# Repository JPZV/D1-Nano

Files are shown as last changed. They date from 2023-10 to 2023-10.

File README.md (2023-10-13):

# D1 Nano

This is a simple project of designs for a D1 Nano, a [D1 Mini](https://www.wemos.cc/en/latest/d1/d1_mini.html) replacement with a smaller size and compatible with ESP32 too!
While I don't have a shop myself, I give the necessary files for making your own free of charge, so feel free to printing your own PCB with your manufacture of choice.

## Advantages

 - Smaller size compared to the D1 Mini
 - All GPIO available with its respective labels
 - Just a few of components to be used
 - Can be powered by 3.3V using 3.3V Test point, or up to 12V by using the 5V Test point (5V is recommended thought)
 - Bigger GPIOs pads compared to the raw MCU
 - Easy to assemble

## Disadvantages

 - Not compatible with breadboards, all GPIOs in use must be soldered in your project
 - [External serial programmer](https://aliexpress.com/item/32842026979.html) must be used
 - No USB connectivity, nor powering by USB

## Assembling

Note: Every component, including the ESP32, can be hand soldered. The GND pad at the back of the ESP32 is not necessary to be soldered.

 0. Download the *.Garber.zip* file for your board in [Releases](https://github.com/JPZV/D1-Nano/releases/latest) and send it to your PCB manufacturer (like PCBWay)
 1. Any resistor marked by R* (R1, R2, R3, etc.) has to be filled with a **1206 10K SMD resistor**.
 2. Any capacitor marked by C* (C1, C2, C3, etc.) has to be filled with a **1206 100nF SMD capacitor** (also named as **1206 0.1uF SMD capacitor**)
 3. Both push buttons are **3x6x2.5mm SMD SPST**.
 4. The regulator (generally marked as **U2**) is an **AMS1117-3.3**.
 5. You can use any type of headers connector for the serial connection, even in any direction that you want. You can even use four Male Jumpers wires when you want to flash without soldering them and then removing them when you finish.
 6. And, for the main MCU, just use the ESP that you want, just be sure to download, buy and assemble the right board (e.g. Use the ESP32 Garber file if you want an ESP32 dev Board). Keep in mind that ESP8266 is also named as ESP12. This board was tested with an ESP12-F and a ESP32-D. The ESP32 Wrover may work but I cannot guarantee it

## Flashing

Note: An [External serial programmer](https://aliexpress.com/item/32842026979.html) is needed

 1. Connect the Serial Programmer to the serial header using Jump Wires.
    - Programmer 5V -> Board 5V
    - Programmer TX -> Board RX
    - Programmer RX -> Board TX
    - Programmer GND -> Board GND
 2. Connect the programmer to your computer
 3. Press and hold the **Reset** button.
 4. Then, press and hold the **Boot** button.
 5. Next, release the **Reset** button while holding the **Boot** button.
 6. Finally, release the **Boot** button. In some ESP32 you have to maintain the **Boot** button pressed while flashing. If you cannot flash your program, then try everything again from step 1 but don't release the **Boot** button until everything is correctly flashed.
 7. Start the Flash process in your program (VS Code, Arduino, ESPHome, Online flasher, etc.) and wait until it finishes.
 8. After it finishes correctly, do a single press in the **Reset** button.

## Contributing

Pull requests are welcome. For major changes, please open an issue first to discuss what you would like to change.

## License

This project uses [MIT license](/LICENSE). This means that you can do whatever you want with this project. You can even make your own board and sell it without needing to give me a commission. But, if you want, you always can [buy me a Coffe](https://ko-fi.com/jpzv5) :)

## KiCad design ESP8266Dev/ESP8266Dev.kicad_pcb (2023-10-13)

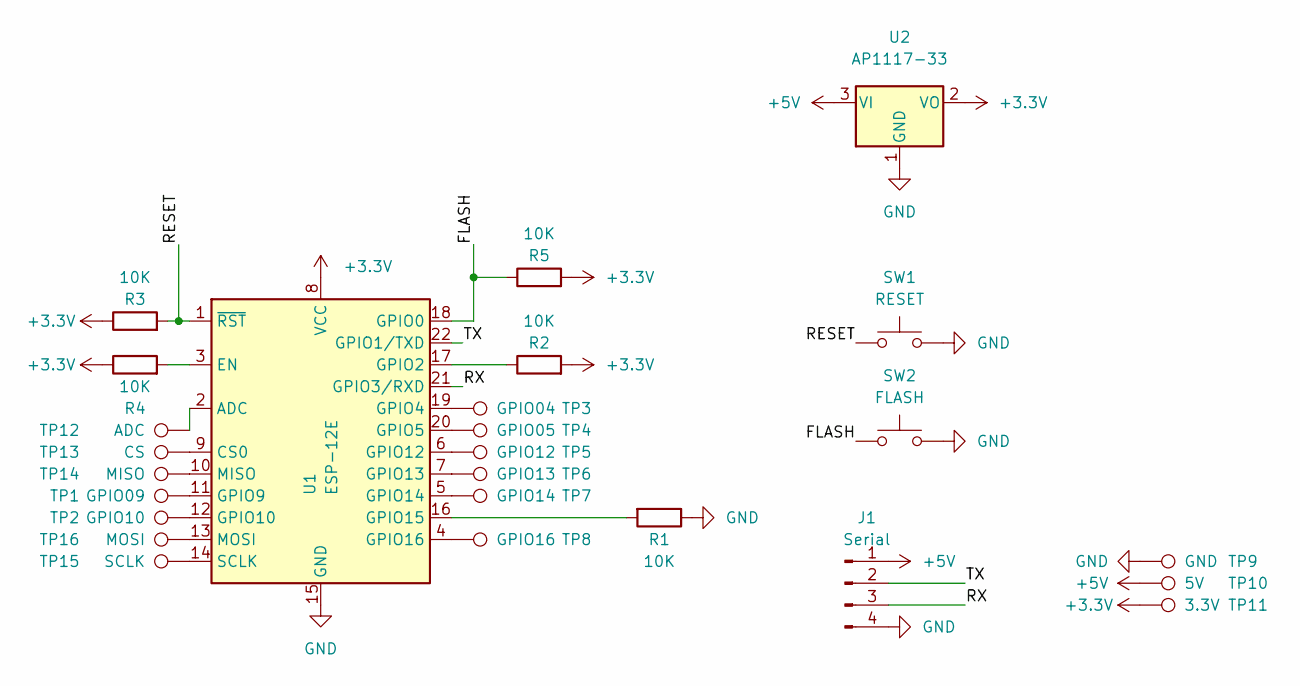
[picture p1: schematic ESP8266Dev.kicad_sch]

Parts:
J1: Serial; PinHeader_1x04_P2.54mm_Vertical
R1, R2, R3, R4, R5: 10K; R_1206_3216Metric_Pad1.30x1.75mm_HandSolder
SW1: RESET; SW_SPST_FSMSM
SW2: FLASH; SW_SPST_FSMSM
TP1: GPIO09; TestPoint_Pad_D2.0mm
TP2: GPIO10; TestPoint_Pad_D2.0mm
TP3: GPIO04; TestPoint_Pad_D2.0mm
TP4: GPIO05; TestPoint_Pad_D2.0mm
TP5: GPIO12; TestPoint_Pad_D2.0mm
TP6: GPIO13; TestPoint_Pad_D2.0mm
TP7: GPIO14; TestPoint_Pad_D2.0mm
TP8: GPIO16; TestPoint_Pad_D2.0mm
TP9: GND; TestPoint_Pad_D2.0mm
TP10: 5V; TestPoint_Pad_D2.0mm
TP11: 3.3V; TestPoint_Pad_D2.0mm
TP12: ADC; TestPoint_Pad_D2.0mm
TP13: CS; TestPoint_Pad_D2.0mm
TP14: MISO; TestPoint_Pad_D2.0mm
TP15: SCLK; TestPoint_Pad_D2.0mm
TP16: MOSI; TestPoint_Pad_D2.0mm
U1: ESP-12E
U2: AP1117-33; SOT-223-3_TabPin2

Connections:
+3.3V: R2.2, R3.1, R4.1, R5.2, TP11.1, U1.8 (VCC), U2.2 (VO)
+5V: J1.1, TP10.1, U2.3 (VI)
/FLASH: R5.1, SW2.1, U1.18 (GPIO0)
/RESET: R3.2, SW1.1, U1.1 (~RST)
/RX: J1.3, U1.21 (GPIO3/RXD)
/TX: J1.2, U1.22 (GPIO1/TXD)
GND: J1.4, R1.1, SW1.2, SW2.2, TP9.1, U1.15 (GND), U2.1 (GND)
unnamed: TP12.1, U1.2 (ADC)
unnamed: TP13.1, U1.9 (CS0)
unnamed: R4.2, U1.3 (EN)
unnamed: R2.1, U1.17 (GPIO2)
unnamed: TP3.1, U1.19 (GPIO4)
unnamed: TP4.1, U1.20 (GPIO5)
unnamed: TP1.1, U1.11 (GPIO9)
unnamed: TP2.1, U1.12 (GPIO10)
unnamed: TP5.1, U1.6 (GPIO12)
unnamed: TP6.1, U1.7 (GPIO13)
unnamed: TP7.1, U1.5 (GPIO14)
unnamed: R1.2, U1.16 (GPIO15)
unnamed: TP8.1, U1.4 (GPIO16)
unnamed: TP14.1, U1.10 (MISO)
unnamed: TP16.1, U1.13 (MOSI)
unnamed: TP15.1, U1.14 (SCLK)

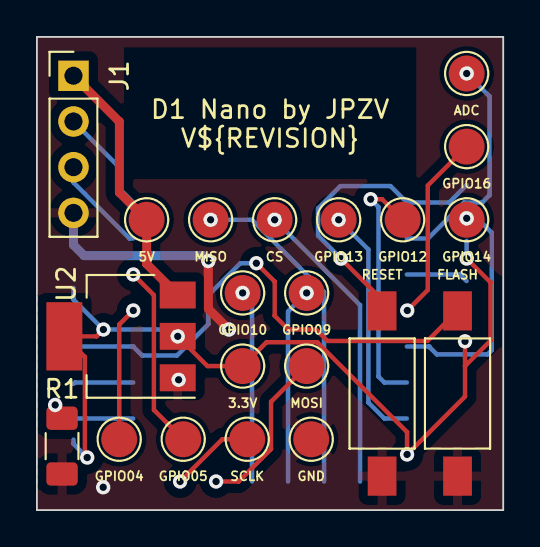
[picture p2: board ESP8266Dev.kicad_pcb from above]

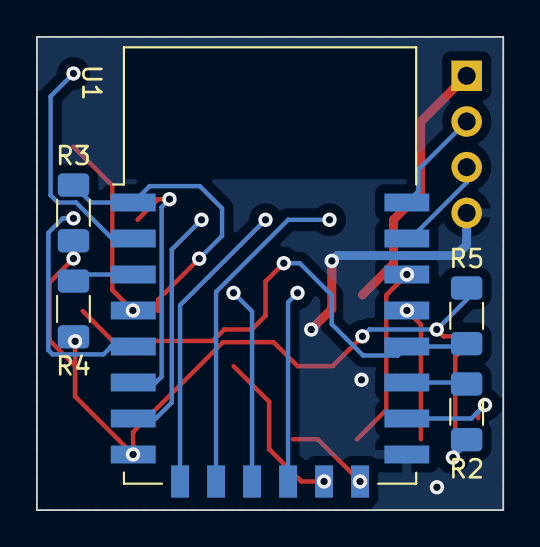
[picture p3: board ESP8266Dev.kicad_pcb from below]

Board: 2 copper layers, 25.9 x 26.3 mm, 26 parts (5 on the bottom side), 23 nets.

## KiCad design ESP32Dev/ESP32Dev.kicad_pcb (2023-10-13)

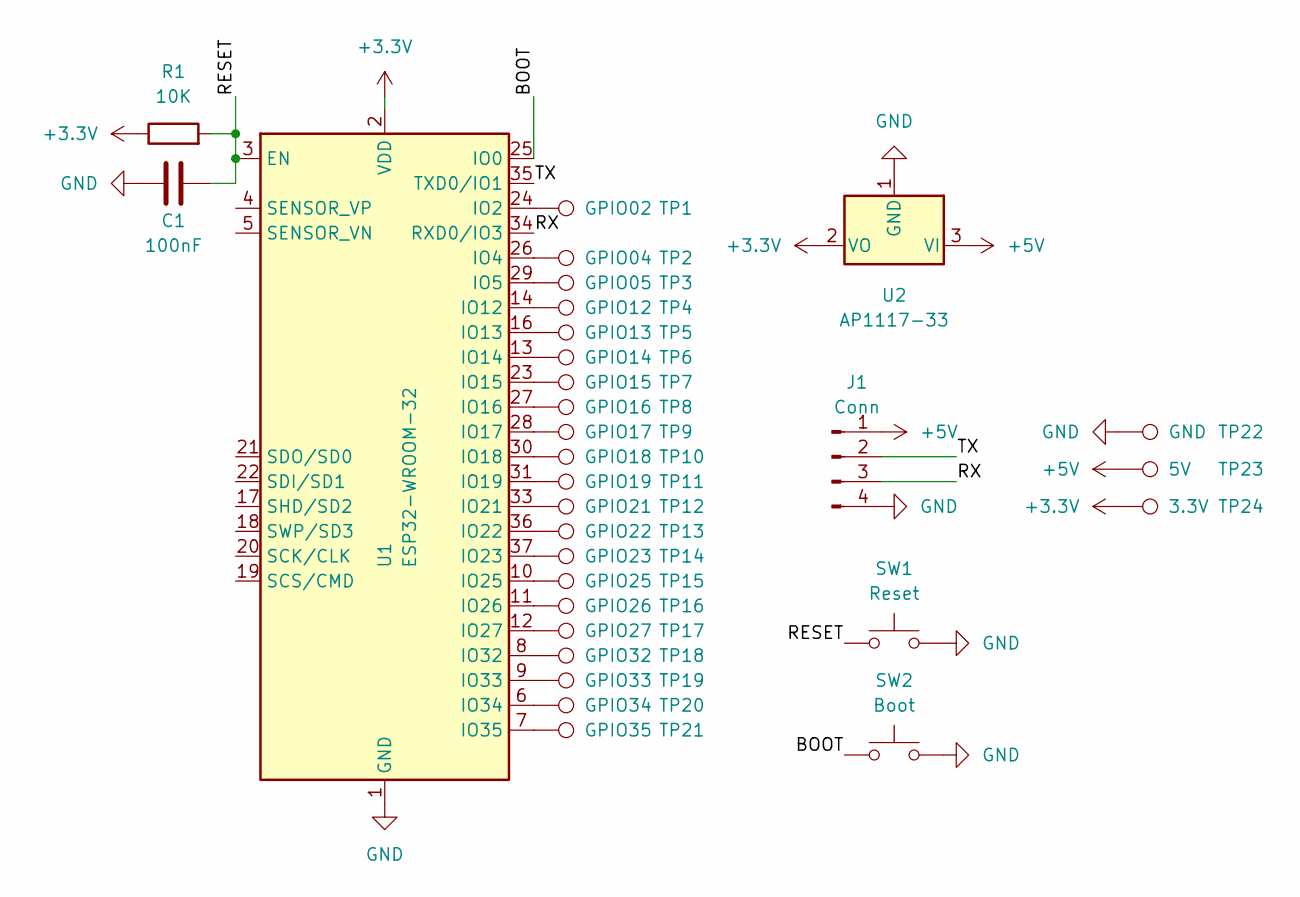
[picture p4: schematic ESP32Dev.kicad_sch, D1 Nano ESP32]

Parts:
C1: 100nF; C_1206_3216Metric_Pad1.33x1.80mm_HandSolder
J1: Conn; PinHeader_1x04_P2.54mm_Vertical
R1: 10K; R_1206_3216Metric_Pad1.30x1.75mm_HandSolder
SW1: Reset; SW_SPST_FSMSM
SW2: Boot; SW_SPST_FSMSM
TP1: GPIO02; TestPoint_Pad_D2.0mm
TP2: GPIO04; TestPoint_Pad_D2.0mm
TP3: GPIO05; TestPoint_Pad_D2.0mm
TP4: GPIO12; TestPoint_Pad_D2.0mm
TP5: GPIO13; TestPoint_Pad_D2.0mm
TP6: GPIO14; TestPoint_Pad_D2.0mm
TP7: GPIO15; TestPoint_Pad_D2.0mm
TP8: GPIO16; TestPoint_Pad_D2.0mm
TP9: GPIO17; TestPoint_Pad_D2.0mm
TP10: GPIO18; TestPoint_Pad_D2.0mm
TP11: GPIO19; TestPoint_Pad_D2.0mm
TP12: GPIO21; TestPoint_Pad_D2.0mm
TP13: GPIO22; TestPoint_Pad_D2.0mm
TP14: GPIO23; TestPoint_Pad_D2.0mm
TP15: GPIO25; TestPoint_Pad_D2.0mm
TP16: GPIO26; TestPoint_Pad_D2.0mm
TP17: GPIO27; TestPoint_Pad_D2.0mm
TP18: GPIO32; TestPoint_Pad_D2.0mm
TP19: GPIO33; TestPoint_Pad_D2.0mm
TP20: GPIO34; TestPoint_Pad_D2.0mm
TP21: GPIO35; TestPoint_Pad_D2.0mm
TP22: GND; TestPoint_Pad_D2.0mm
TP23: 5V; TestPoint_Pad_D2.0mm
TP24: 3.3V; TestPoint_Pad_D2.0mm
U1: ESP32-WROOM-32
U2: AP1117-33; SOT-223-3_TabPin2

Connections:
+3.3V: R1.1, TP24.1, U1.2 (VDD), U2.2 (VO)
+5V: J1.1, TP23.1, U2.3 (VI)
/BOOT: SW2.1, U1.25 (IO0)
/RESET: C1.2, R1.2, SW1.1, U1.3 (EN)
/RX: J1.3, U1.34 (RXD0/IO3)
/TX: J1.2, U1.35 (TXD0/IO1)
GND: C1.1, J1.4, SW1.2, SW2.2, TP22.1, U1.1 (GND), U1.15 (GND), U1.38 (GND), U1.39 (GND), U2.1 (GND)
unnamed: TP1.1, U1.24 (IO2)
unnamed: TP2.1, U1.26 (IO4)
unnamed: TP3.1, U1.29 (IO5)
unnamed: TP4.1, U1.14 (IO12)
unnamed: TP5.1, U1.16 (IO13)
unnamed: TP6.1, U1.13 (IO14)
unnamed: TP7.1, U1.23 (IO15)
unnamed: TP8.1, U1.27 (IO16)
unnamed: TP9.1, U1.28 (IO17)
unnamed: TP10.1, U1.30 (IO18)
unnamed: TP11.1, U1.31 (IO19)
unnamed: TP12.1, U1.33 (IO21)
unnamed: TP13.1, U1.36 (IO22)
unnamed: TP14.1, U1.37 (IO23)
unnamed: TP15.1, U1.10 (IO25)
unnamed: TP16.1, U1.11 (IO26)
unnamed: TP17.1, U1.12 (IO27)
unnamed: TP18.1, U1.8 (IO32)
unnamed: TP19.1, U1.9 (IO33)
unnamed: TP20.1, U1.6 (IO34)
unnamed: TP21.1, U1.7 (IO35)

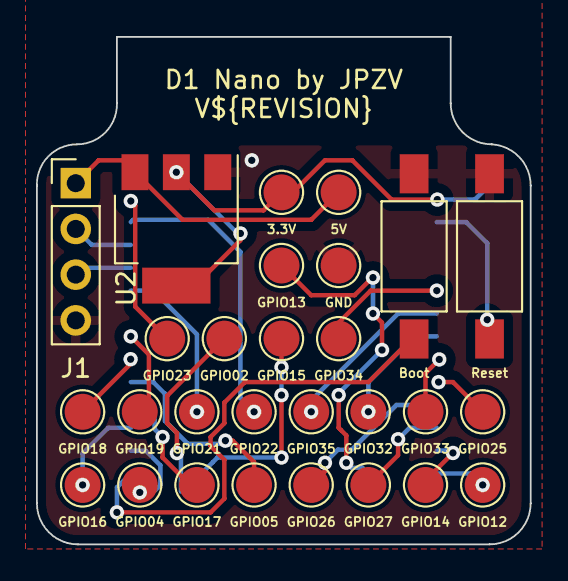
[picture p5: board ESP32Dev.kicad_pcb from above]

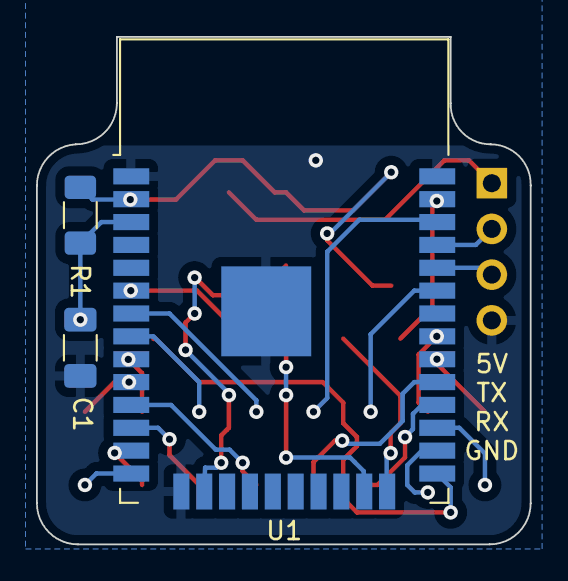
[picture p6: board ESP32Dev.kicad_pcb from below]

Board: 2 copper layers, 27.4 x 28.2 mm, 31 parts (3 on the bottom side), 28 nets.

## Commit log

2023-10-11 Added ESP32 Dev Board
    [ESP32Dev.kicad_pcb, ESP32Dev.kicad_sch]
2023-10-11 ESP32: Fixed via overlapping GPIO19 text
    [ESP32Dev.kicad_pcb]
2023-10-11 ESP32: Fixed capacitor value
    [ESP32Dev.kicad_sch]
2023-10-13 Added ESP8266Dev Board
    [ESP32Dev.kicad_pcb, ESP32Dev.kicad_sch, ESP8266Dev.kicad_pcb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]
